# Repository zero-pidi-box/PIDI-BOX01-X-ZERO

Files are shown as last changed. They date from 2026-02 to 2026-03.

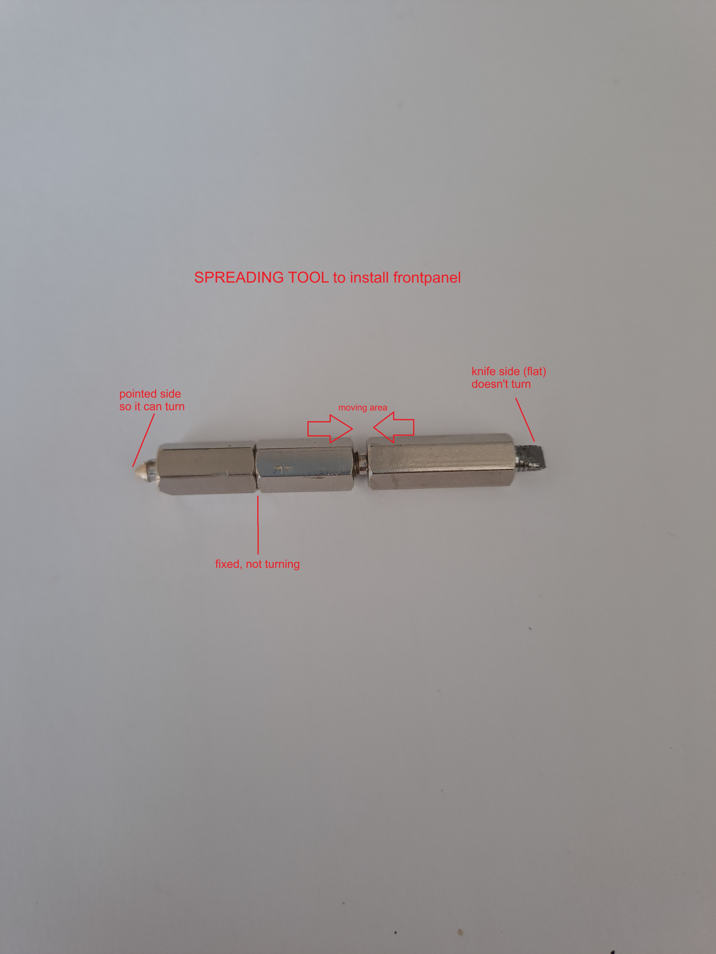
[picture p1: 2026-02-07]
DOCUMENTS all/MECHANICAL and Drawings/PIDI-BOX-spreading tool .jpg

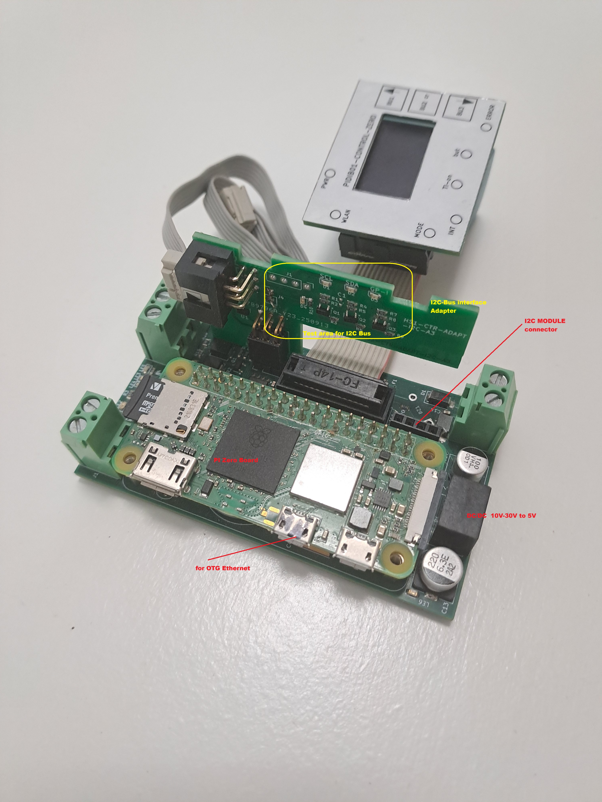
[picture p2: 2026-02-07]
MODULES/CONTROLLER-PI/PI-ZERO-installed.jpg

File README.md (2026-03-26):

# PIDI-BOX01
# A PI-ZERO 2W based modular DIN Rail controller SYSTEM

## OVERVIEW:
Instead of using one controller box with a fixed number of IO’s, 
this system is modular,  
The controller module contains a minimum of interfaces and is expandable with a lot of
* IO MODULES like:  
* **RELAYS /SSR ,**
* **optical INPUTS,**
* **ANALOG inputs,**
* **light sensors RF-transceivers** 
* and much more.

All modules are connected to the controller module via a I2C-Bus.  
Flat cable 6 pin IDC.  
The i2c-bus is 5V buffered:  GND, +5V supplied by the controller  
SDA,SCL and a bidirectional line, usable for interrupts or any control.  
**System supply voltage:  12 V DC (the Controller module only: 10 to 28V)**  

### **Mechanical:**  
DIN Rail enclosures:   Camdenboss CNMB/2/KIT and CNMB/3/KIT  
make sure you use this enclosures, all board are designed for that enclosures !!  

---  
---   

#### **MODULES:**

**PI Zero 2W based controller:**  

CNMB enclosure Size 3:  53,4mm  
    
TERMINALS:  
2 pole terminal: Supply voltage: 10V DC to 24V DC (this module only, or 5V with USB-C adapter)  
2 pole terminal: digital OPTO-INPUT  
3 pole terminal: 1-WIRE interface  
All terminals support 26-12AWG calbles

Front Panel with:
3 touch keys,  
128x64 OLED display  
and 6 led’s (reverse mounted)

**On board:**  
RTC 3132 with Bat. CR2032, status led’s, beeper, I2C driver for external bus,  
I2C buffer, DC/DC converter 12 to 5V 3A.  
Front panel connecto.  
   
**PI Zero 2w module socket**. 
   
**IO:**  
1x digital OPTO in  
1x 1-WIRE interface (GND, sig.,+5V)  
1x UART 4 pin header (no terminal)  
1x I2C-BUS  6 pin  IDC socket.  
 
---  

**DIGITAL 6 port  Relays  (on):**

CNMB enclosure Size 2:  36mm  
Supply voltage: 12V DC  
2x 6 pole terminal for power and RELAY outs  
IO Controller  PCF8574A  (PCF8574)  
After PW-on all relays in off state. Is controlled by bit 7.  
**Front panel** with 6 TEST BUTTONs for the outputs and status LED’s  

---  

**DIGITAL 6 port OPTICAL  INPUTS:**

CNMB enclosure Size 2:  36mm  
Supply voltage: 12V DC  
2x 6 pole terminal for power and INPUTS  
IO Controller  PCF8574A  (PCF8574)  
Front panel with 6 TEST BUTTONs for the outputs and status LED’s  

---  

**ADC 4 CHANNEL (ADS1115)  potential-free inputs:**  
  
CNMB enclosure Size 2:  36mm  
Supply voltage: 12V DC  
2 pole terminal for power  
6 pole terminal for 4 channels of ADC (4), GND and power source.  
    
Internal power source (200mA) 4-8V DC (for sensors on analog 0 to 3)  
  
ADC input and power source are potential free from the system.  
The I2C interface is isolated from the system bus  
 with a **ADUM1250** from Analog Devices.  

There are two versions of the ADC 4:  
A1 is assembled and tested.  
A2 only is available as a KICAD design and has not yet been assembled or tested.  
The A2 version is optimized and can be addressed via  
**four I2C addresses**:    
0x48: ADDR Pin with  GND , 0x49: ADDR Pin with   VDD  
0x4A: ADDR Pin with   SDA, 0x4B: ADDR Pin with   SCL  

---  

**This was just a short summary for quick information.**      
For more details please read the documentation  
available  in the directory DOCUMENTS.  
From time to time I will add individual documentation or data sheets.  

**General information:**  
The hardware I am designing since 3 years for a garden watering system  
in different versions.  
All modules have been tested in reality.  
Code and documents are  **without any guarantee** for any user.

**NO  VDE, CE or other certificates are available.**   
Do not use relay outputs and inputs with high voltage or on main supply.

**All printed boards are designed with KICAD 9**  
including labels, front panels and some drawings for buttons breakthroughs.  
There are no bom's for the boards.  
They should be generated by the user themselves in KICAD.

**Module BOM’s are available in the documents area.**  

**Al outputs or inputs** are designed for low voltage up to 24V, relays up to 48V.   
All analog and direct inputs are ESD protected (TVS 12 V bidirectional)
Not all components are fully optimized, it’s up to the users to do that.

**Meaning of the project name:**

   **PIDI-BOX**  is the project name.  
   That means : Raspberry **PI** Zero **DI**nrail **-BOX**  

**Where to get all Parts?**  
The printed boards I always order from  JLCPCB  <https://jlcpcb.com/es?from=Wolfgang>  
Quality and service is excellent, parts are inexpensive with a very fast delivery.  
![]()

90% of the parts (IC, led ..)  I bought via AliExpress. 

The **CNMB** enclosures you **only can get from a Camdenboss distributor**.  
The 5.08mm Terminals you can buy from camdenbos or other manufacturers.

**Just by the way:**  
I developed the system for myself. In a fiew places it is not optimally dimensioned.  
It's up to you to optimize.  
For me it is sufficient because everything works in practical use.

I would be happy to hear from interested co-developers or users of my hardware.  
That would be an incentive for me to continue and expand the system with additional hardware.  
By the way, documentation is not intended for production.  
Therefore only the most necessary in my opinion.  
There are many documents and clues in the photos or as text.  
Before you start, try to understand my ideas, then the documentation should be enough.  
All GERBER Files are actual, so you can start an assembly imediately.  

With the age of 76,  I don't know how much longer I can work on the project.  
I would be happy if someone continued it.  

If you badly need help, here my special project e-mail :  <PIDI-BOX01@gmx.net>.  
I will try to respond as soon as possible, but it can take a while.  
Wolfgang Mansfeld 02-2026

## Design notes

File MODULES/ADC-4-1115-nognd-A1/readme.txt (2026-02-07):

This Directory contains the BOM to build the MODULE.
Enclosures, other mechanicals like screws, nuts, cables, distance holders
and the assembled BOARDS e.g.  

The BORDS used will have their own bom list in the KICAD directories.
It is up to the designer to generate them.

If availabe,  videos/fotos for the module can be located here.

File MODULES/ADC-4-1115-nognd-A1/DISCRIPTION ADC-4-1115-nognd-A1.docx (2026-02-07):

General preliminary description of the 4 channel Analog Modul

System PIDI-BOX-01

DATAS:

ADC 4 CHANNEL (ADS1115) potential-free inputs:

CNMB enclosure Size 2: 36mm

Supply voltage: 12V DC

2 pole terminal (26-12AWG) for power

6 pole terminal (26-12AWG) for 4 channels of ADC (4), GND

and internal, potential free power source (200mA) 4-8V DC

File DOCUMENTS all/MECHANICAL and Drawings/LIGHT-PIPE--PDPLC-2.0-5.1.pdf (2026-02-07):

# LIGHT-PIPE used for PIDI-BOX Modules

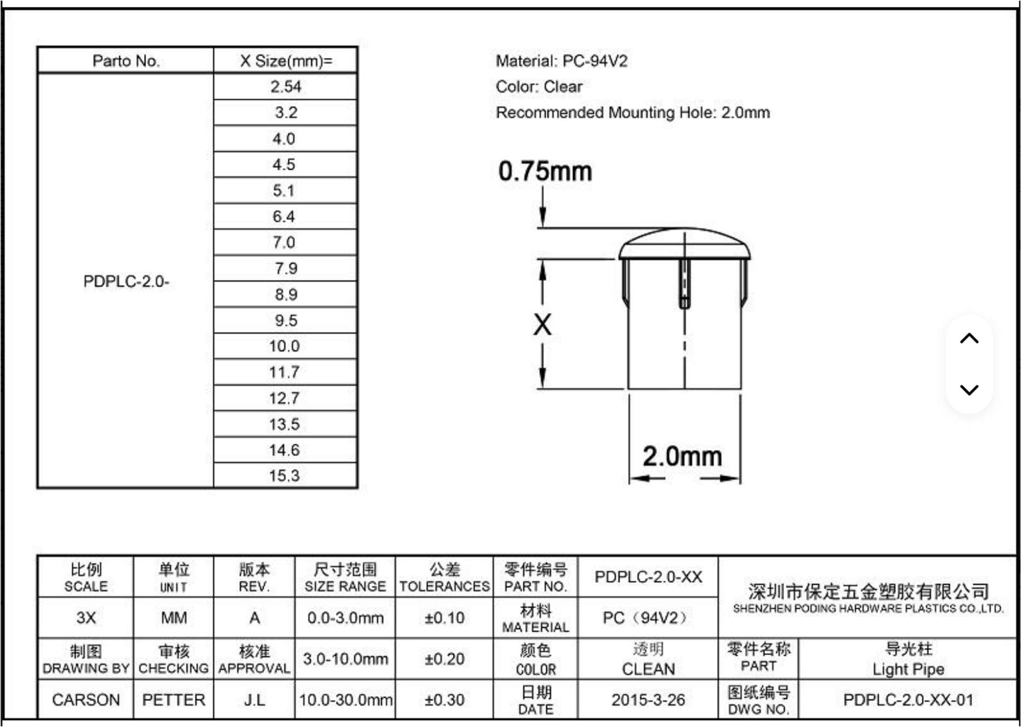
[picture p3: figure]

X = 5,1mm, part no: PDPLC-2.0-5.1
Link : https://podingcorp.en.alibaba.com/productgrouplist-820925231/%C3%B81_0_2_0mm.html
Available on AliExpress as well !!!

Shenzhen Poding Hardware Plastics Co., Ltd. or chose other manufacturers

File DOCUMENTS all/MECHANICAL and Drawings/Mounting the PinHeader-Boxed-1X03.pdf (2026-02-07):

## Mounting the PinHeader-Boxed-1X03

## 2.54 horizontal Wuerth_61200621721

Used on the following PCBs:

PIDI-BOX-01-ADAPT-I2C-A1, PIDI-BOX-01-IO-6-CTRL74-A1

The pin headers for the external I2C bus must be mounted very carefully. To do this, it is necessary to seal the socket with a double-sided adhesive strip before soldering approx. 0.3mm thickness, so that it does not tilt during soldering.
Due to the adhesive strip (as in the photo), the socket is automatically not directly on the board. Thus, the socket is a little further
away from the PCB guide.

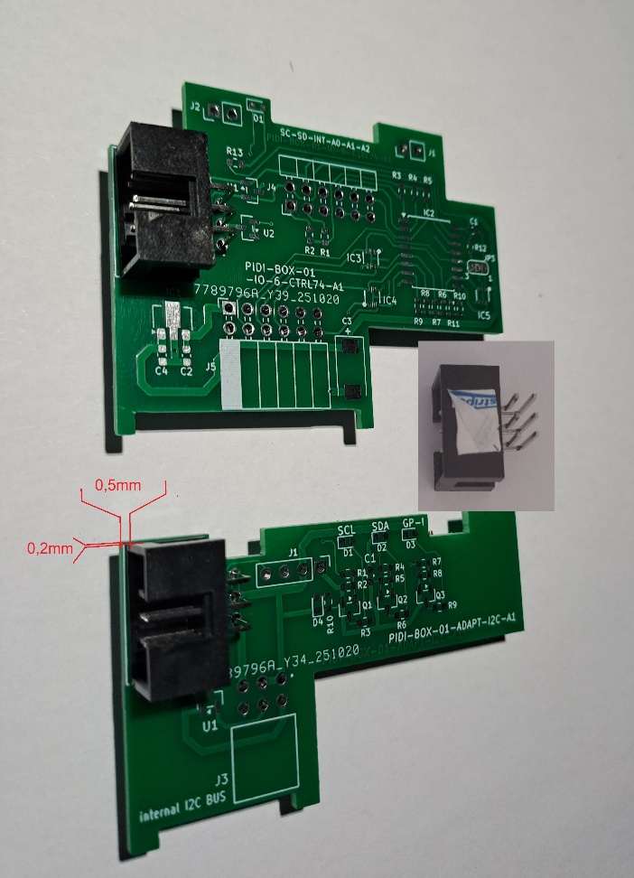
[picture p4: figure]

About the photo:
Distances from the PCB edges:

Links
to the breakthrough in the housing: 0.5mm +0.1
Top
to the case : 0.2mm.

The dimensions apply to all PCBs with this I"C-Bus pin header.

The socket on the right shows how the double-sided adhesive strip should be mounted CENTRALLY.

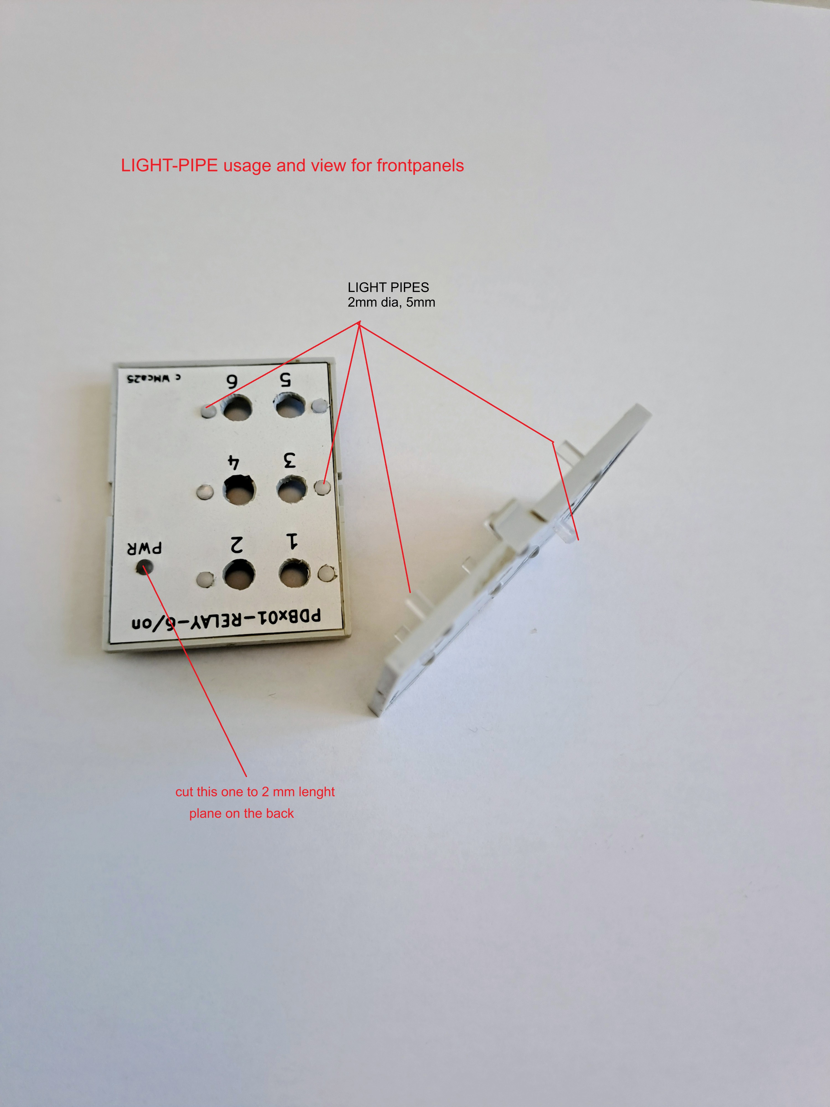
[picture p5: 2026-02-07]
DOCUMENTS all/MECHANICAL and Drawings/MODULES used LIGHT-PIPE.jpg

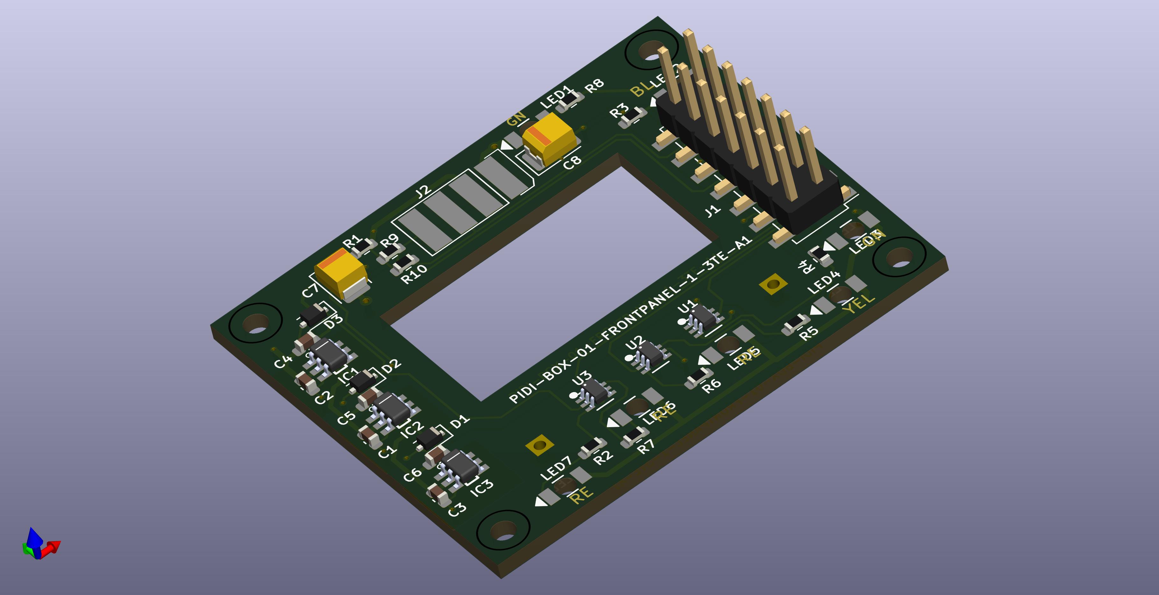
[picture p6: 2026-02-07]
KICAD_BOARDS/PIDI-BOX-01-FRONTPANEL-1-3TE-A1/PIDI-BOX-01-FRONTPANEL-1-3TE-A1.jpg

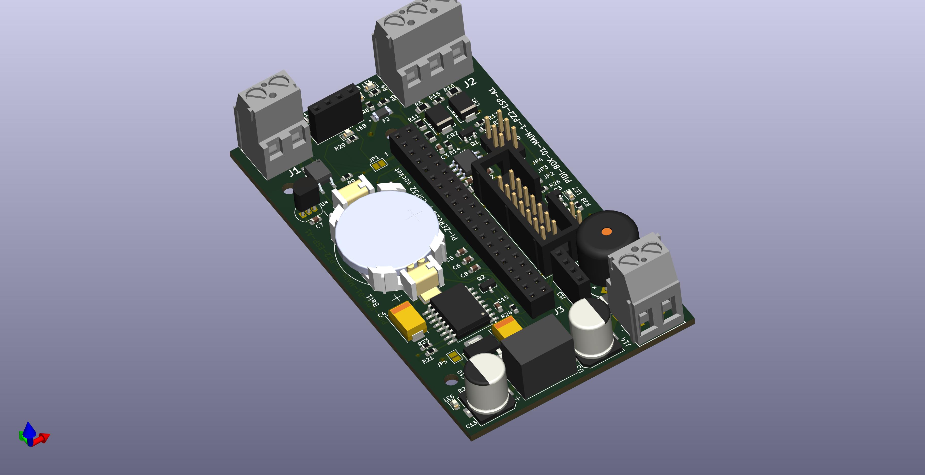
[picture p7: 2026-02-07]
KICAD_BOARDS/PIDI-BOX-01-MAIN-1-PZ2-ESP-A1/PIDI-BOX-01-MAIN-1-PZ2_ESP-A1.jpg

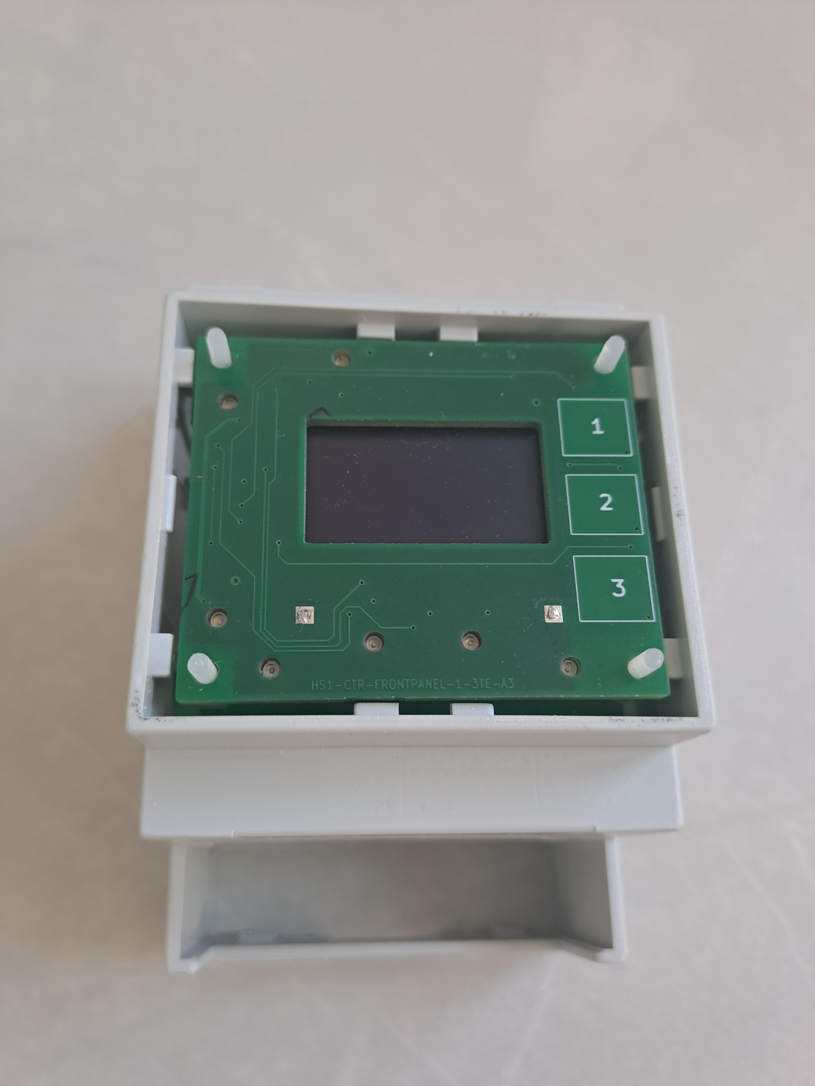
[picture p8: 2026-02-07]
FOTOS and 3D/3TE-displ-mounting 2.jpg

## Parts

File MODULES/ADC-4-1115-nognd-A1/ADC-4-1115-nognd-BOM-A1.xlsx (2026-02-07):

ADC-4-1115-nognd-BOM-A1
POS | DESCRIPTION | PARTNUMBER | Qty | MANUFACTURER | DISTRIBUTOR | Internet
1 | Enclosure DinRail (2M) | CNMB/2/KIT | 1 | Camdenboss | Reichelt DE/ES | https://www.camdenboss.com
1 | Assembled PIDI-BOX board ADC main | PIDI-BOX-01-ADC-4-MAIN-A1 |  | own KICAD board | none | none
1 | Assembled PIDI-BOX board I2C Interface | PIDI-BOX-01-ADAPT-I2C-A1 |  | own KICAD board | none | none
1 | Drilled frontplate from CNMB/2/KIT | from CNMB/2/KIT |  | Camdenboss | none | none
1 | LED 2mm green to install in frontplate | any |  | any | any | any
2 | wire to connect for LED | any |  | any | any | any

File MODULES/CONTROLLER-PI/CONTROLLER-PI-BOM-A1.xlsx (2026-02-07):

System-CONTROLLER-PI-BOM-A1
POS | DESCRIPTION | PARTNUMBER | Qty | MANUFACTURER | DISTRIBUTOR | Internet
1 | (3M) DIN Rail Module Box Cover | CNMB/3/PC - CLEAR | 1 | Camdenboss | Reichelt DE/ES | https://www.camdenboss.com
2 | Enclosure DinRail (3M) | CNMB/3/KIT | 1 | Camdenboss | Reichelt DE/ES | https://www.camdenboss.com
3 | Assembled PIDI-BOX board SYSTEM Controller | PIDI-BOX-01-MAIN-1-PZ2_ESP-A1 | 1 | own KICAD board | none | none
4 | Assembled PIDI-BOX board I2C Interface | PIDI-BOX-01-ADAPT-I2C-A1 | 1 | own KICAD board | none | none
5 | Assembled PIDI-BOX FRONTPANEL with OLED a | PIDI-BOX-01-FRONTPANEL-1-3TE-A1 | 1 | own KICAD board | none | none
6 | PIDI-BOX display mounting frame | PIDI-BOX-01-DISPLAY-MOUNTINGFRAME-A1 | 1 | own KICAD board | none | none
7 | Flatcable 100mm with 2 IDC connectors 14pin | none | 1 | buy or assemble on your own | Ali Express/others | none
8 | M2 Nylon PCB Standoff 5mm, thread 6mm + screw | any supplier (ali express) | 4 |  | any supplier (ali express)
9 | M2,5 spacer bolt 8mm len, internal thread only | any supplier (ali express) | 4
10 | M2,5 spacer bolt 8mm len, internal thread only | any supplier (ali express) | 8
11 | M2,5 x 6mm screws
12 | PI ZERO Board without HEADER | PI Zero 2W | 1 | Raspberry | any
13 | Header 2X20 pins , pitch 2,54 | any
 | Make sure to order PI Zero 2W without header.
 | The 40 pin header must be soldered on the DOWNSIDE of the module
 | The orignal , for HUTS, is upside. Wrong for this project.

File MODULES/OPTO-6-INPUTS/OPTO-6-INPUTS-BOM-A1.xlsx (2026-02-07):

OPTO-6-INPUTS-BOM-A1
POS | DESCRIPTION | PARTNUMBER | Qty | MANUFACTURER | DISTRIBUTOR | Internet
1 | Enclosure DinRail (2M) | CNMB/2/KIT | 1 | Camdenboss | Reichelt DE/ES | https://www.camdenboss.com
2 | Assembled PIDI-BOX board OPTO 6 in main | PIDI-BOX-01-DIGIN-6-OPTO-MAIN-A1 | 1 | own KICAD board | none | none
3 | Assembled PIDI-BOX board 6 button and led keypad | PIDI-BOX-01-RELSW-6-BUTTONS-A1 | 1 | own KICAD board | none | none
4 | Assembled PIDI-BOX board side adapter for keypad | PIDI-BOX-01-IO-6-SIDEB-A1 | 1 | own KICAD board | none | none
5 | Assembled PIDI-BOX board I2C int, 6 IO controller | PIDI-BOX-01-IO-6-CTRL74-A1 | 1 | own KICAD board | none | none
6 | Drilled frontplate from CNMB/2/KIT / 6 buttons | frontplate from CNMB/2/KIT | 1 | own modified/drilled | none | none

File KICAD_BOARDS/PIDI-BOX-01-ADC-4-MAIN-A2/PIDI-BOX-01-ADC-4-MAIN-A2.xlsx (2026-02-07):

Reference | Qty | Value | Footprint | DNP
C1,C3,C4,C5,C6,C7,C8,C9,C11,C13,C15,C16,C17,C18,C21 | 15 | 100nF | Capacitor_SMD:C_0603_1608Metric
C2,C10,C20 | 3 | 100uF | Capacitor_SMD:CP_Elec_8x10.5,Capacitor_Tantalum_SMD:CP_EIA-3528-21_Kemet-B,Capacitor_Tantalum_SMD:CP_EIA-6032-28_Kemet-C
C12 | 1 | 10uF | Capacitor_SMD:C_0805_2012Metric
C14,C19 | 2 | 4,7uF | Capacitor_SMD:C_0805_2012Metric
CR1,CR2,CR3,CR4,CR5 | 5 | SM6T12CA | MYlib_GLOBAL:SMB_STM
D1 | 1 | LED rt | LED_SMD:LED_0603_1608Metric
D2,D3 | 2 | LED gn | LED_SMD:LED_0603_1608Metric,LED_THT:LED_D3.0mm
D4 | 1 | US2BA | Diode_SMD:D_SMA
IC1 | 1 | HCPL-354-000E | MYlib_GLOBAL:HCPL-354-000E
J1 | 1 | Conn_01x10_Pin | Connector_PinSocket_2.54mm:PinSocket_1x10_P2.54mm_Vertical
J2 | 1 | Conn_02x03_Odd_Even | Connector_PinHeader_2.54mm:PinHeader_2x03_P2.54mm_Vertical
J3 | 1 | Conn_02x02_Odd_Even | Connector_PinHeader_2.54mm:PinHeader_2x02_P2.54mm_Vertical
J4,J5 | 2 | Conn_02x01 | Connector_PinHeader_2.54mm:PinHeader_1x02_P2.54mm_Vertical
J6,J7 | 2 | CTB0709_3 | MYlib_GLOBAL:CTB07093
J8 | 1 | CTB0709_2 | MYlib_GLOBAL:CTB07092
J9,J10 | 2 | Conn_01x01 | Connector_PinHeader_2.54mm:PinHeader_1x01_P2.54mm_Vertical
JP1 | 1 | Jumper_2_Open | Jumper:SolderJumper-2_P1.3mm_Open_Pad1.0x1.5mm
L1 | 1 | 6,8uH | Inductor_SMD_Wurth:L_Wurth_WE-GF-3225
PS1 | 1 | IA1209S-2WS | Converter_DCDC:Converter_DCDC_XP_POWER-IAxxxxS_THT
Q1 | 1 | BC817 | Package_TO_SOT_SMD:SOT-23
R1,R10,R24,R25,R26,R27 | 6 | 10 | Resistor_SMD:R_0603_1608Metric
R2,R3,R7,R8,R9 | 5 | 4K7 | Resistor_SMD:R_0603_1608Metric
R4 | 1 | 5K6 | Resistor_SMD:R_0603_1608Metric
R5,R6 | 2 | 100 | Resistor_SMD:R_0603_1608Metric
R11,R12,R13,R14,R29,R30,R31 | 7 | 10K | Resistor_SMD:R_0603_1608Metric
R15,R16,R17,R18 | 4 | 820 | Resistor_SMD:R_0603_1608Metric
R19 | 1 | 8K2 | Resistor_SMD:R_0603_1608Metric
R20,R21,R22,R23 | 4 | 1K5 | Resistor_SMD:R_0603_1608Metric
R28 | 1 | 6K8 | Resistor_SMD:R_0603_1608Metric
RV1 | 1 | 500 | Potentiometer_SMD:Potentiometer_Bourns_3314G_Vertical
RV2,RV3,RV4,RV5 | 4 | 1K | Potentiometer_THT:Potentiometer_Bourns_3296W_Vertical
U1 | 1 | AMS1117-3.3 | Package_TO_SOT_SMD:SOT-223-3_TabPin2
U2 | 1 | ADuM1250 | Package_SO:SOIC-8_3.9x4.9mm_P1.27mm
U3 | 1 | AMS1117CD | Package_TO_SOT_SMD:SOT-223-3_TabPin2
U4 | 1 | ADS1115IDGS | Package_SO:TSSOP-10_3x3mm_P0.5mm

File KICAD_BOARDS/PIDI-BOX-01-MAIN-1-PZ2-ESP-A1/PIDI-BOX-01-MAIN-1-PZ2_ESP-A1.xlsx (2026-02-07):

Reference | Value | Qty | Footprint
C1,C2,C5,C6,C7,C8,C10,C11,C12,C14,C15,C16,C19 | 100nF | 13 | Capacitor_SMD:C_0603_1608Metric
R4,R9,R13,R15,R25,R26,R28,R30,R31 | 4K7 | 9 | Resistor_SMD:R_0603_1608Metric
R3,R6,R7,R8,R16,R17,R19,R29 | 1K5 | 8 | Resistor_SMD:R_0603_1608Metric
R5,R10,R11,R12 | 2.2 | 4 | Resistor_SMD:R_0805_2012Metric
LE1,LE4,LE7,LE8 | red | 4 | LED_SMD:LED_0603_1608Metric
R21,R23,R24 | 10K | 3 | Resistor_SMD:R_0603_1608Metric
R14,R20,R27 | 100 | 3 | Resistor_SMD:R_0603_1608Metric
R1,R2,R22 | 2K7 | 3 | Resistor_SMD:R_0603_1608Metric,Resistor_SMD:R_0805_2012Metric
JP2,JP3,JP4 | 0 | 3 | Resistor_SMD:R_0805_2012Metric
Q1,Q3 | BSS138 | 2 | Package_TO_SOT_SMD:SOT-23
LE3,LE5 | blue | 2 | LED_SMD:LED_0603_1608Metric
JP1,JP5 | Jumper_2_Open | 2 | Jumper:SolderJumper-2_P1.3mm_Open_Pad1.0x1.5mm
J4,J8 | Conn_01x01_Pin | 2 | Connector_PinHeader_2.54mm:PinHeader_1x01_P2.54mm_Vertical
J1,J14 | CTB0709_2 | 2 | MYlib_GLOBAL:CTB07092
F1,F2 | 1206L075THYR | 2 | MYlib_GLOBAL:1206L05015YR
CR1,CR2 | SM6T12CA | 2 | MYlib_GLOBAL:SMB_STM
C3,C18 | 10nF | 2 | Capacitor_SMD:C_0603_1608Metric
U5 | AMS1117-3.3 | 1 | Package_TO_SOT_SMD:SOT-223-3_TabPin2
U4 | DS18B20 | 1 | Package_TO_SOT_THT:TO-92_Inline
U3 | LC78_05-3.0 | 1 | MYlib_GLOBAL:VREG_LC78_05-3.0
U2 | DS3231M | 1 | Package_SO:SOIC-16W_7.5x10.3mm_P1.27mm
U1 | PCA9517AD_118 | 1 | MYlib_GLOBAL:SOIC127P600X175-8N
R18 | 4.7 | 1 | Resistor_SMD:R_0805_2012Metric
Q2 | BC817 | 1 | Package_TO_SOT_SMD:SOT-23
LE6 | yellow | 1 | LED_SMD:LED_0603_1608Metric
LE2 | green | 1 | LED_SMD:LED_0603_1608Metric
J13 | MODUL / I2C | 1 | Connector_PinSocket_2.54mm:PinSocket_1x04_P2.54mm_Vertical
J12 | Digital out | 1 | Connector_PinHeader_2.54mm:PinHeader_1x02_P2.54mm_Vertical
J11 | Conn_02x07_Odd_Even | 1 | Connector_IDC:IDC-Header_2x07_P2.54mm_Vertical
J9 | Conn_02x03_Odd_Even | 1 | Connector_PinHeader_2.54mm:PinHeader_2x03_P2.54mm_Vertical
J5 | Conn_01x03_Pin | 1 | Connector_PinSocket_2.54mm:PinSocket_1x04_P2.54mm_Vertical
J3 | PI_ZERO_2W/ESP32 | 1 | MYlib_GLOBAL:PIDI_PinSocket_2x20_P2.54mm_Vertical
J2 | CTB0709_3 | 1 | MYlib_GLOBAL:CTB07093
IC1 | HCPL-354-000E | 1 | MYlib_GLOBAL:HCPL-354-000E
FB1 | FerriteBead | 1 | Inductor_SMD:L_2010_5025Metric_Pad1.52x2.65mm_HandSolder
D1 | US2BA | 1 | Diode_SMD:D_SMA
C17 | 100uF | 1 | Capacitor_SMD:CP_Elec_8x10
C13 | 220uF | 1 | Capacitor_SMD:CP_Elec_8x10
C9 | 470UF | 1 | Capacitor_Tantalum_SMD:CP_EIA-7343-31_Kemet-D_Pad2.25x2.55mm_HandSolder
C4 | 470uF | 1 | Capacitor_Tantalum_SMD:CP_EIA-7343-31_Kemet-D
BZ1 | Buzzer | 1 | Buzzer_Beeper:Buzzer_12x9.5RM7.6
Bat1 | BU2032SM | 1 | MYlib_GLOBAL:BAT_BU2032SM-BT-GTR

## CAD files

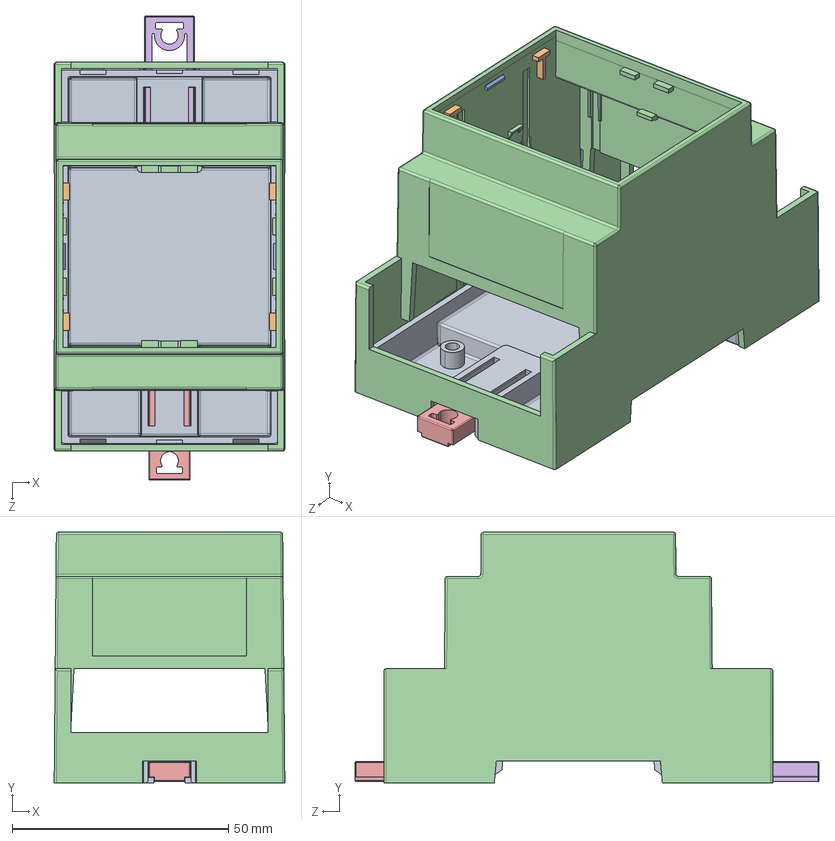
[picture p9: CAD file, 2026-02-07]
DOCUMENTS all/MECHANICAL and Drawings/CNMB-3-2.STEP
53.4 x 58.0 x 107.4 mm
CNMB-3-Base
CNMB-3-2-Top
CNMB-CW
CNMB-CB

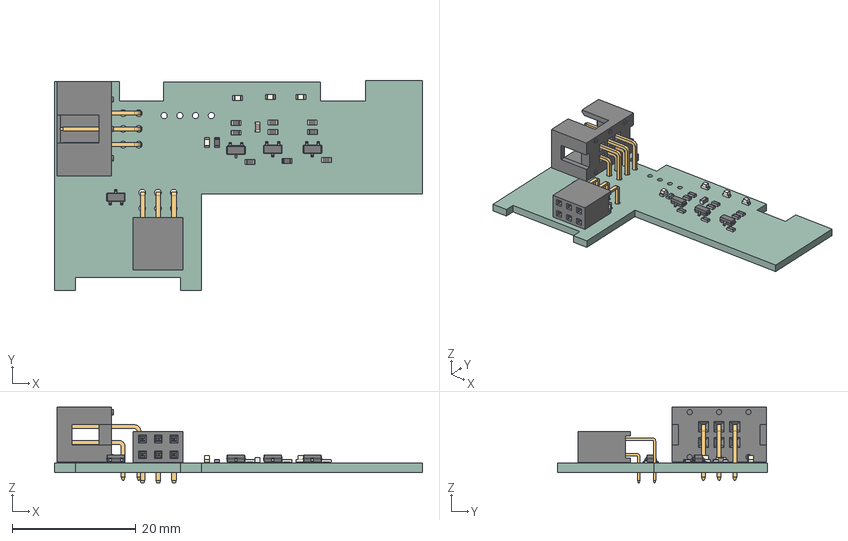
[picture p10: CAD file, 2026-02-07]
KICAD_BOARDS/PIDI-BOX-01-ADAPT-I2C-A1/PIDI-BOX-01-ADAPT-I2C-A1.step
59.5 x 33.9 x 12.2 mm
SOT-23 x 4
R_0603_1608Metric x 10
6130xx243121_PIN x 3
6130xx243121_PIN_G x 3
LED_0603_1608Metric x 4
6120xx21721_PIN x 3
6120xx21721_PIN_LONGUE x 3
C_0603_1608Metric
PIDI-BOX-01-ADAPT-I2C-A1_PCB

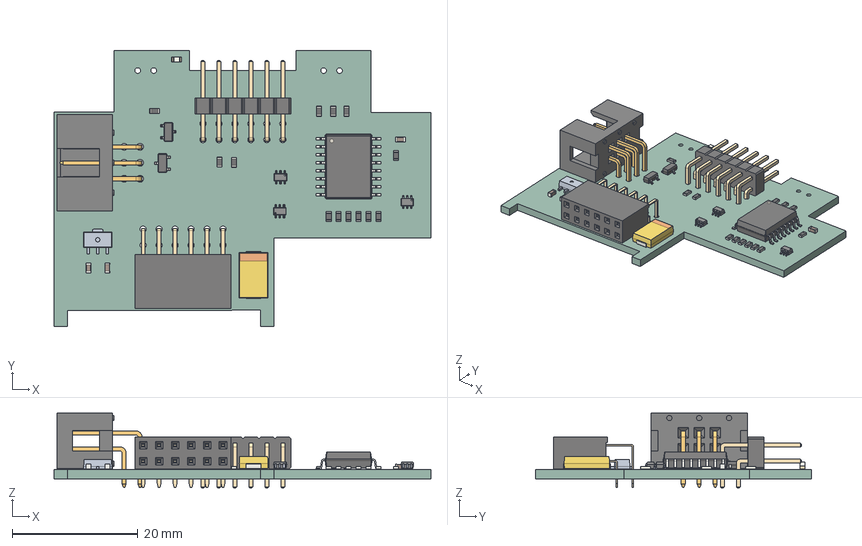
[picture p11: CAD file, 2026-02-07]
KICAD_BOARDS/PIDI-BOX-01-IO-6-CTRL74-A1/PIDI-BOX-01-IO-6-CTRL74-A1.step
59.9 x 43.9 x 11.9 mm
R_0603_1608Metric x 13
PinHeader_2x06_P2.54mm_Horizontal
SOT-23 x 2
6120xx21721_PIN x 3
6120xx21721_PIN_LONGUE x 3
C_0603_1608Metric x 3
PIDI-BOX-01-IO-6-CTRL74-A1 1.14.1
PinSocket_2x06_P2.54mm_Horizontal
PUMH10,115 x 3
LED_0603_1608Metric
CP_EIA-7343-20_Kemet-V
SOIC-16W_7.5x10.3mm_P1.27mm
PIDI-BOX-01-IO-6-CTRL74-A1_PCB

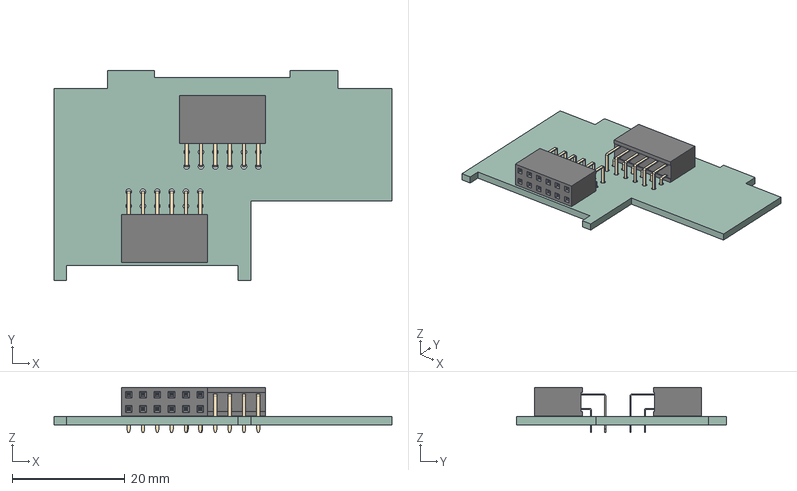
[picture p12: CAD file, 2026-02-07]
KICAD_BOARDS/PIDI-BOX-01-IO-6-SIDEB-A1/PIDI-BOX-01-IO-6-SIDEB-A1.step
59.9 x 37.3 x 7.98 mm
PinSocket_2x06_P2.54mm_Horizontal x 2
PIDI-BOX-01-IO-6-SIDEB-A1_PCB

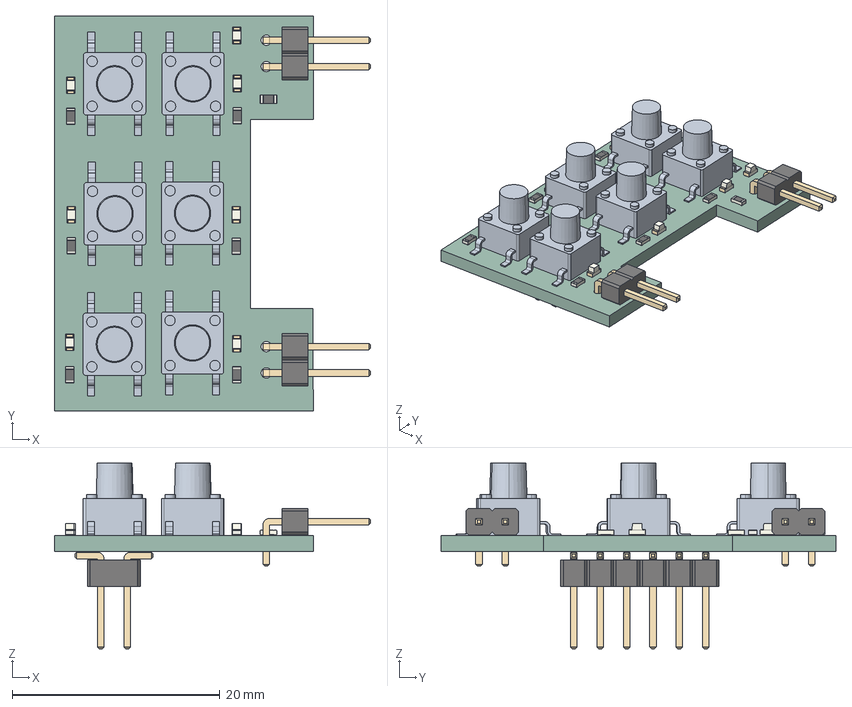
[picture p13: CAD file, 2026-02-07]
KICAD_BOARDS/PIDI-BOX-01-RELSW-6-BUTTONS-A1/PIDI-BOX-01-RELSW-6-BUTTONS-A1.step
30.4 x 38.0 x 17.9 mm
R_0603_1608Metric x 7
LED_0603_1608Metric x 7
SW_tactile-6X6_smd x 6
PinHeader_1x02_P2.54mm_Horizontal x 2
PinHeader_2x06_P2.54mm_Vertical_SMD
PIDI-BOX-01-RELSW-6-BUTTONS-A1_PCB

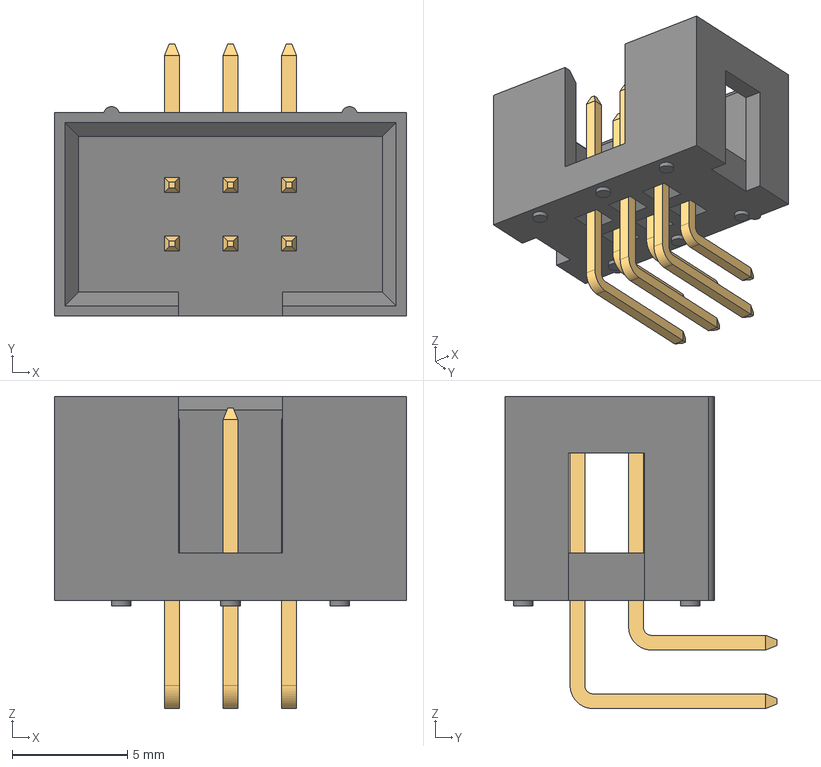
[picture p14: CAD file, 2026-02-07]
KICAD_BOARDS/PIDI_specialparts_library/MYlib_GLOBAL_3dshapes/6120XX21721_61200621721.step
15.3 x 11.8 x 13.6 mm
6120xx21721_PIN x 3
6120xx21721_PIN_LONGUE x 3

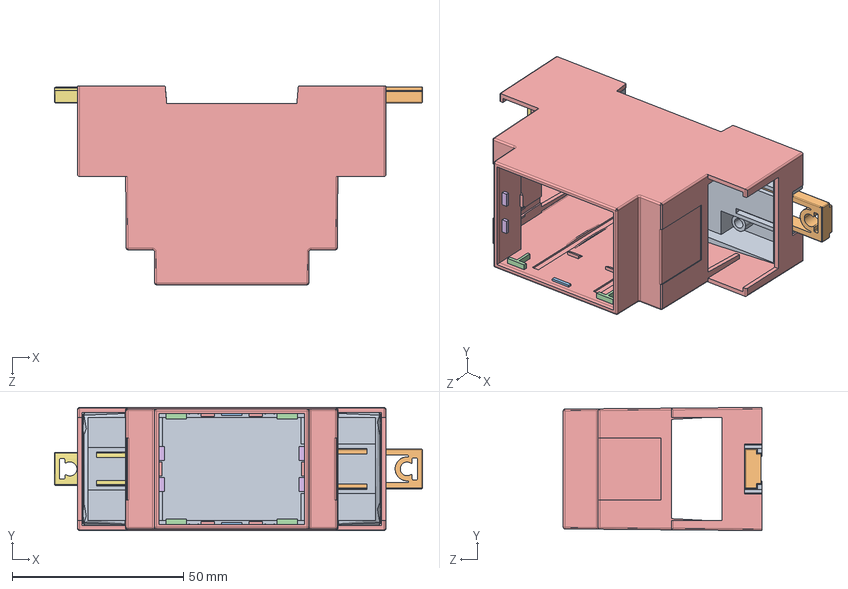
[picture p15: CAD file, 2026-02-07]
DOCUMENTS all/MECHANICAL and Drawings/CNMB-2-2.STEP
107.5 x 36.0 x 58.0 mm
CNMB-CB
CNMB-2-2-Top-1
CNMB-CW
CNMB-2-Base-1

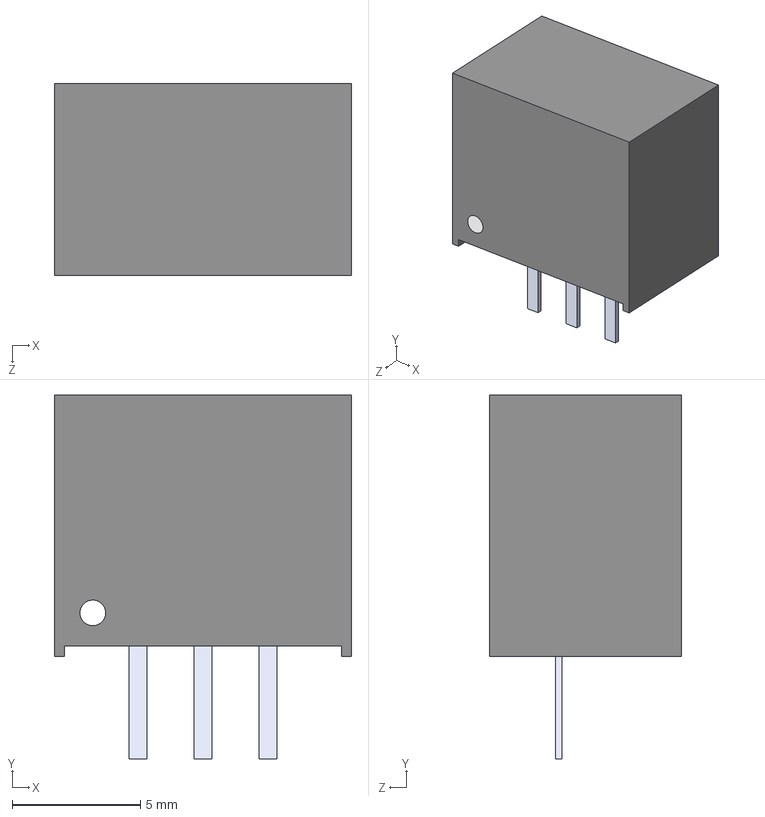
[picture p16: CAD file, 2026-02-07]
KICAD_BOARDS/PIDI_specialparts_library/MYlib_GLOBAL_3dshapes/LC78_05-3.0.step
11.6 x 14.2 x 7.50 mm

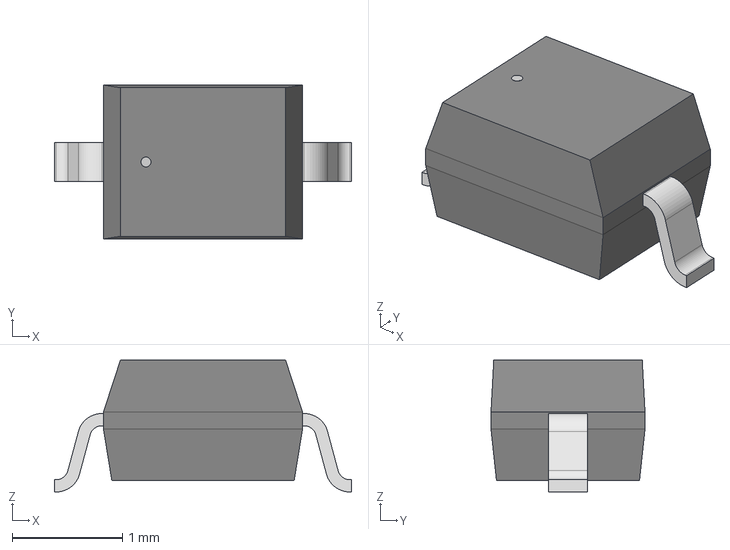
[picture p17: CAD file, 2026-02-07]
KICAD_BOARDS/PIDI_specialparts_library/MYlib_GLOBAL_3dshapes/SOD323_DIO.step
2.69 x 1.40 x 1.20 mm

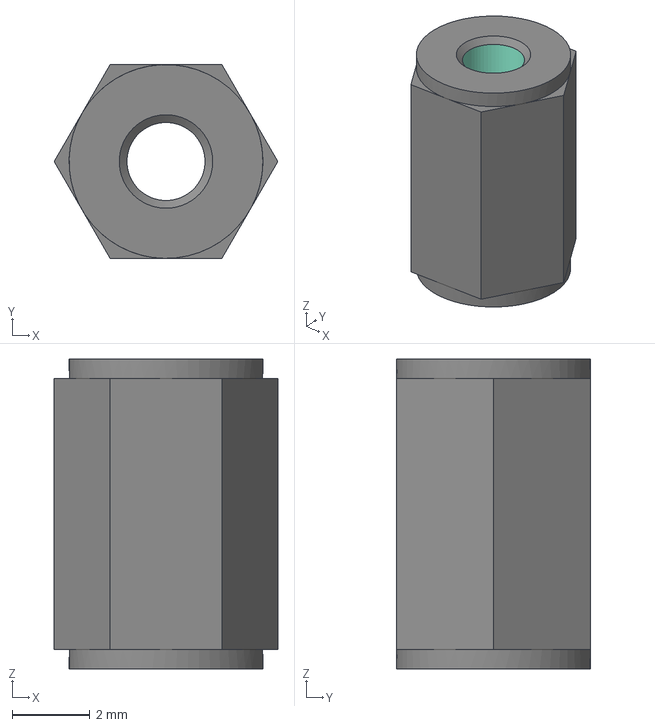
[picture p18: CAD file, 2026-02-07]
KICAD_BOARDS/PIDI_specialparts_library/MYlib_GLOBAL_3dshapes/Download_STEP_970080155+(rev1)(2).stp
5.77 x 5.00 x 8.00 mm

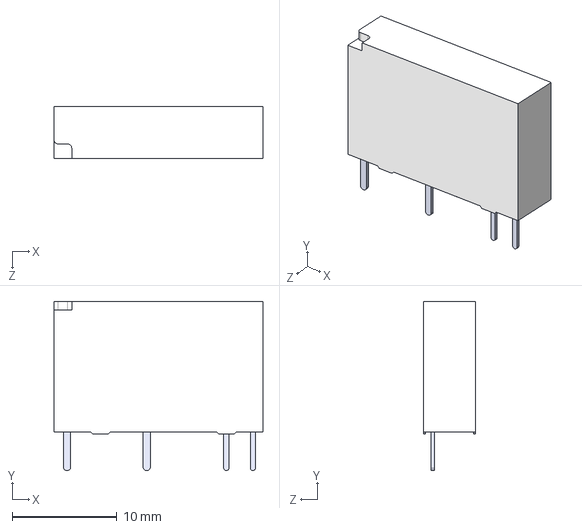
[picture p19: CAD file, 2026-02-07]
KICAD_BOARDS/PIDI_specialparts_library/MYlib_GLOBAL_3dshapes/HF49FD_005-1H12T.step
20.0 x 16.2 x 5.00 mm

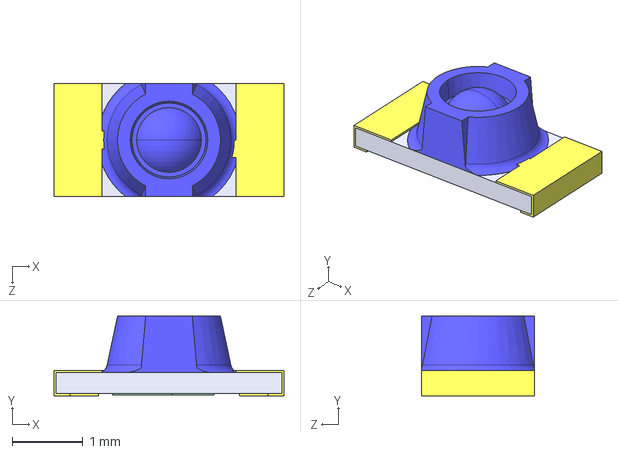
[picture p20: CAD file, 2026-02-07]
KICAD_BOARDS/PIDI_specialparts_library/MYlib_GLOBAL_3dshapes/25-21 Step.STEP
3.26 x 1.13 x 1.60 mm

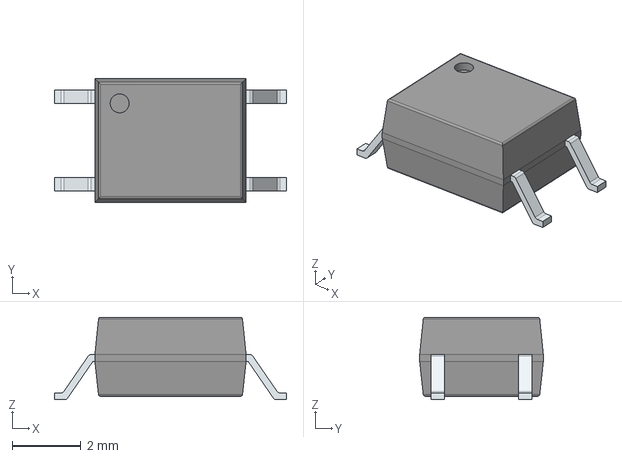
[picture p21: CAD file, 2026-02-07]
KICAD_BOARDS/PIDI_specialparts_library/MYlib_GLOBAL_3dshapes/HCPL-354-000E.stp
6.75 x 3.60 x 2.40 mm
PinsArrayLR

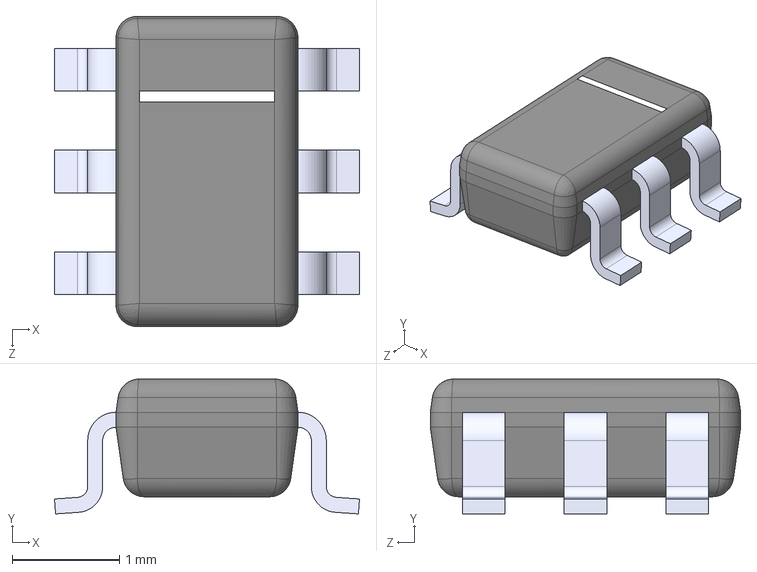
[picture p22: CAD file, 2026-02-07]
KICAD_BOARDS/PIDI_specialparts_library/MYlib_GLOBAL_3dshapes/TTP223-BA6.STEP
2.85 x 1.26 x 2.90 mm

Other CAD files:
KICAD_BOARDS/PIDI_specialparts_library/MYlib_GLOBAL_3dshapes/würth_12pol_613012243121.stp
KICAD_BOARDS/PIDI_specialparts_library/MYlib_GLOBAL_3dshapes/L_Wurth_WE-GF-3225.step
KICAD_BOARDS/PIDI_specialparts_library/MYlib_GLOBAL_3dshapes/SW_tactile-6X6_smd.stp
KICAD_BOARDS/PIDI_specialparts_library/MYlib_GLOBAL_3dshapes/BU2032SM-BT-GTR.STEP
KICAD_BOARDS/PIDI_specialparts_library/MYlib_GLOBAL_3dshapes/1206L075THYR.STEP
KICAD_BOARDS/PIDI_specialparts_library/MYlib_GLOBAL_3dshapes/3214X-1-102E.stp
KICAD_BOARDS/PIDI_specialparts_library/MYlib_GLOBAL_3dshapes/CTB0709_2.stp
KICAD_BOARDS/PIDI_specialparts_library/MYlib_GLOBAL_3dshapes/L_Wurth_WE-GF-4532.step
KICAD_BOARDS/PIDI_specialparts_library/MYlib_GLOBAL_3dshapes/PCA9517AD_118.step
KICAD_BOARDS/PIDI_specialparts_library/MYlib_GLOBAL_3dshapes/PUMH10,115.STEP
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

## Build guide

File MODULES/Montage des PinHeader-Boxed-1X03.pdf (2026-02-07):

## Montage des PinHeader-Boxed-1X03

## 2,54-horizontal-Wuerth_61200621721

Auf folgenden PCB’s verwendet:

PIDI-BOX-01-ADAPT-I2C-A1, PIDI-BOX-01-IO-6-CTRL74-A1

Die Pin Header für den externen I2C-Bus müssen sehr sorgfältig montiert werden. Hierzu ist es notwendig die Buchse vor dem Löten mit einem doppelseitige Klebestreifen
ca. 0,3mm Stärke zu fixieren, damit diese sich beim Löten nicht verkantet.
Durch den Klebestreifen (wie im Foto) liegt die Buchse automatisch nicht direkt auf der Platine.
Beim Einbau in ein Gehäuse, ist darauf zu
achten, | dass | der | Führungssteg
entsprechend in den Schlitz gleitet.
Erst dann ist die Platine richtig fixiert.

Zum Foto:
Abstände von den Leiterplatten Kanten:

Links
zum Durchbruch im Gehäuse: 0,5mm +0,1
Oben
zum Gehäuse : 0,2mm.

Die Maße gelten für alle Leiterplatten mit diesem I“C-Bus Pin-Header.

Die Buchse rechts zeigt, wie der
doppelseitige | Klebestreifen | MITTIG


montiert werden muss. Sonst bleibt kein Spalt für den Führungssteg !!!!

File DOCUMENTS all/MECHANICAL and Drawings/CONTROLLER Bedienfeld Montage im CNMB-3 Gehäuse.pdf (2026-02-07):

Bedienfeld Montage:
Controller Modul im CNMB/3/ Gehäuse

Die Nylon Abstandshalter müssen zuerst auf dem Rahmen montiert werden. Dann wird der Rahmen in angegebener Richtung eingebaut Wichtig ist die Position des Rahmens beim Einbau.

Der oene Ausschnitt muss vom I2C Ausschnitt weg zeigen. Wie im Bild.

Der Montagerahmen darf nicht gewaltsam in das Gehäuse gedrückt werden !!!!
Die kleinen Nasen im Plastikgehäuse zur

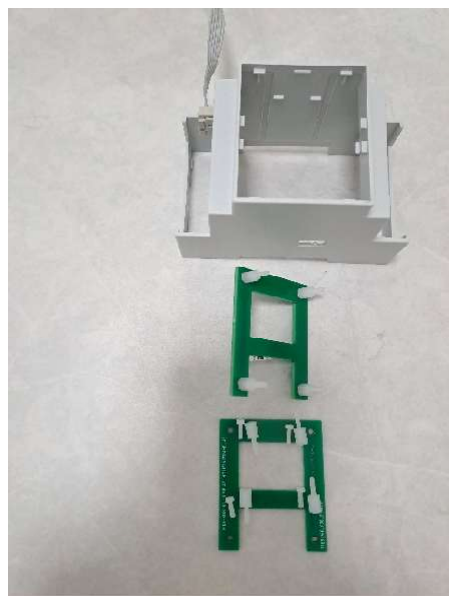
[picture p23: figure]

Arretierung des Rahmens, sind sehr zerbrechlich.

Deshalb solltet Ihr das kleine Eigenbau Werkzeug verwenden.
Das Spreizwerkzeug hilft den Rand des Gehäuses so weit auseinander zu drücken, bis man den Rahmen leicht einsetzen kann.

Spreizen und
dann den
Rahmen von
unten einsetzen

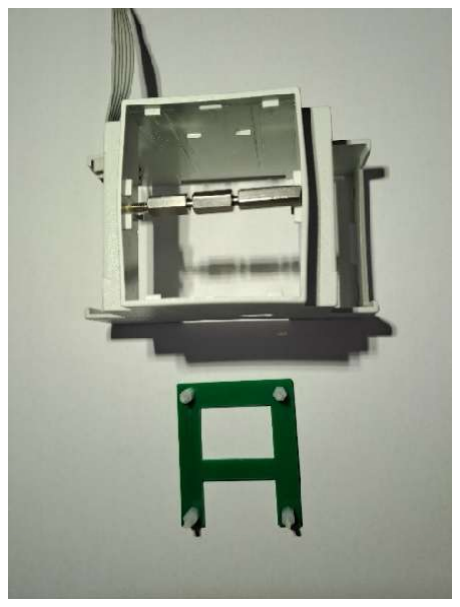
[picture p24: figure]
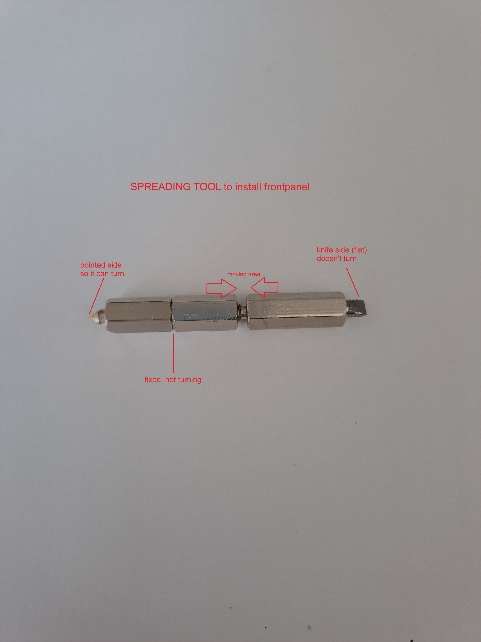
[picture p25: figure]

Danach das Werkzeug vorsichtig entfernen !!

Nun das Bedienfeld auf die 2mm Kunststo Gewinde aufstecken. Bitte beachten: Die Aussparung im Rahmen muss sich links befinden. Denn auf dieser Seite sitzt der Steckverbinder der Leiterplatte.

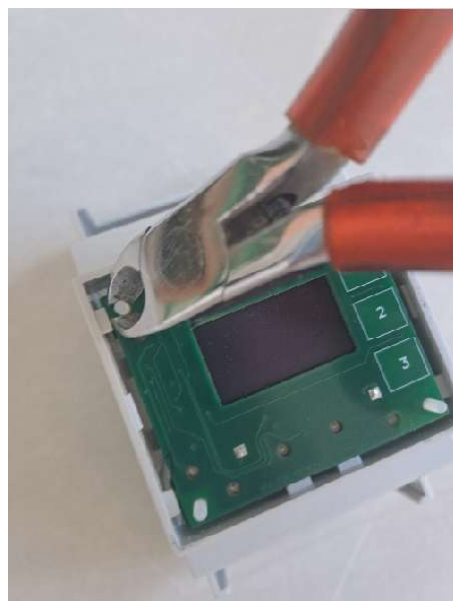
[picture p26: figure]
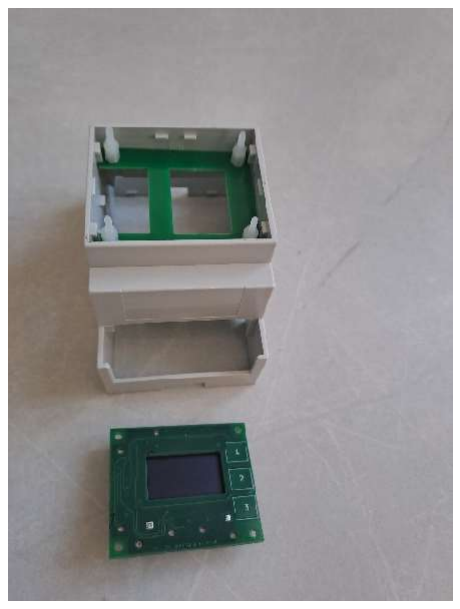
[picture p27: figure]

Die Gewindebolzen bündig mit der Leiterplatte abschneiden.

Die Leiterplatte nicht ankleben oder fixieren. Das Ganze ist schwimmend gelagert und wird mit der durchsichtigen Frontplatte ( zusätzlich zum Gehäuse bestellen, siehe MODULE BOM) abgedeckt.

Auf die Leiterplatte kann eine Beschriftete Folie direkt aufgeklebt werden. Die drei rechten kapazitiven Tasten werden vom Sensor IC automatisch angepasst. Näheres im Dokument.

FERTIG

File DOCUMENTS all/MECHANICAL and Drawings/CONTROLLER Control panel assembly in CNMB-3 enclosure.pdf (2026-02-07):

Control panel Mounting
of the controller module in the CNMB/3/ housing

The nylon spacers must first be mounted on the frame. Then the frame is installed in the specified direction
The position of the frame during installation is important.

The open cutout must face away from the I2C cutout. As in the picture.

The mounting frame must not be forcibly pressed into the housing !!!
The small lugs in the plastic housing for locking the frame are very fragile.


That's why you should use the small DIY tool.
The spreading tool helps to push the edge of the case apart until you can easily insert the frame.

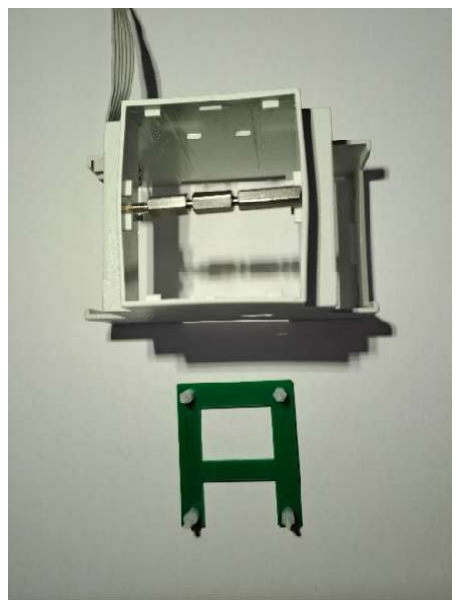
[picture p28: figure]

Spread and then
insert the frame
from below


After that, carefully remove the tool !!

Please note: The recess in the frame must be on the left.

This is because the connector of the printed circuit board is located on this side.
Now attach the control panel to the 2mm plastic thread.

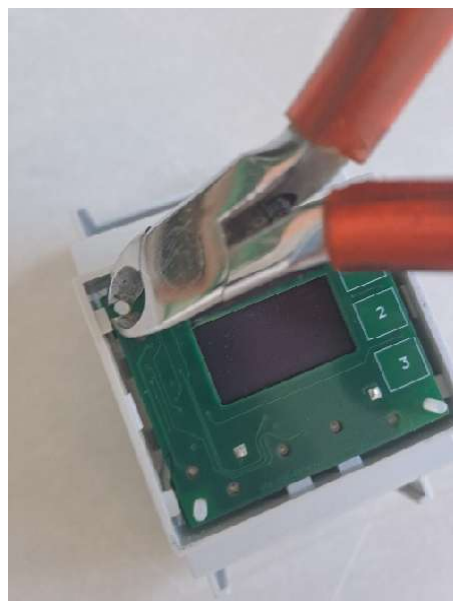
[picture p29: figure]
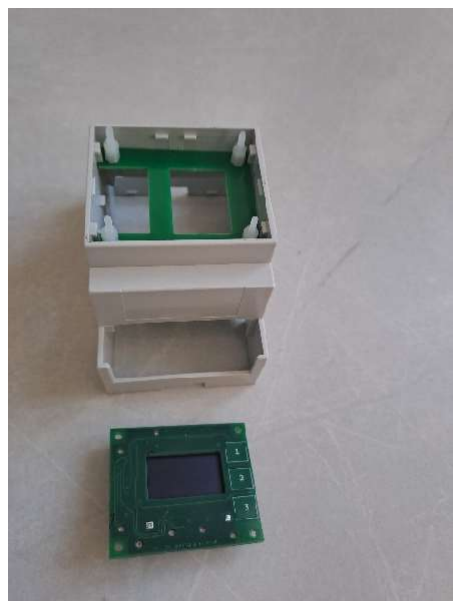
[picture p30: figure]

Cut the threaded bolts flush with the PCB.

Do not glue or fix the PCB. The whole thing is floating
and is covered with the transparent front panel (order in addition to the housing, see MODULE BOM).

A labeled foil can be glued directly to the printed circuit board.
The three right capacitive buttons are automatically adjusted by the sensor IC. More details in the document.

DONE

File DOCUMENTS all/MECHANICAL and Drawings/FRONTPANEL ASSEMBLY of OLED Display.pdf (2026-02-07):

FRONTPANEL OLED Display Assembly on printed circuit board PIDI-BOX-01-FRONTPANEL-1-3TE-A1

Before mounting the OLED display, the two fixing pins must be soldered onto it. This must not protrude on the front after soldering. Otherwise, the panel cannot be installed in the module housing and no labeled foil can be glued on.

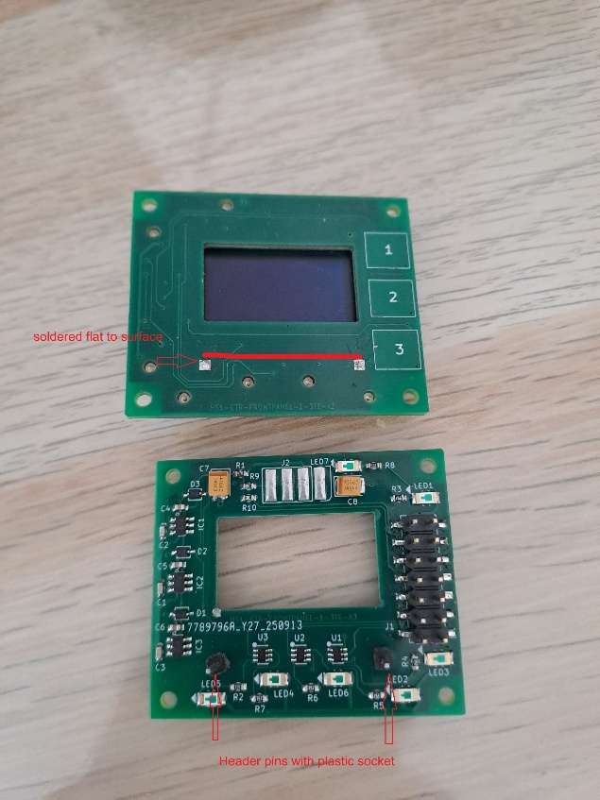
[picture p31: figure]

Individual contacts of a pin strip, which is used to fix the distance of the display, are suitable for this purpose. The display is located on this side on the bases of the pins. On the contact side of the display, this rests on the tantalum capacitors. This means that the distance to the PCB is large enough and fixed.

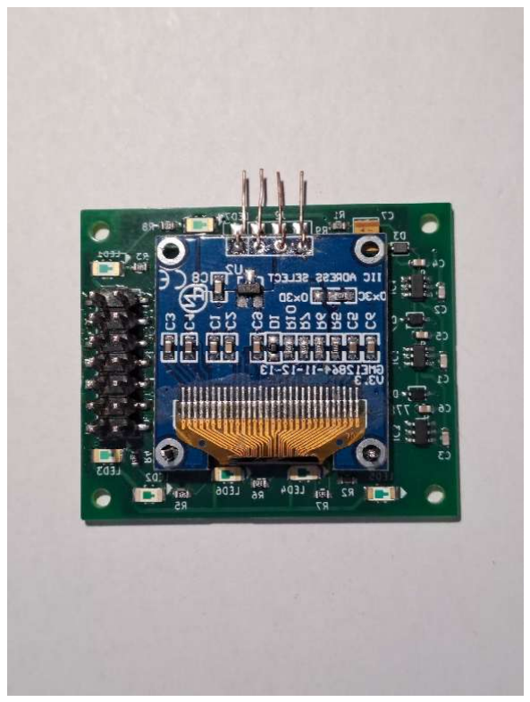
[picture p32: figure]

The GME12864-11-1 display should be ordered without pins, as there are no holes for it. These would be ill-suited for a front-facing labeling film.

Instead of the pins, four copper wires are soldered on.

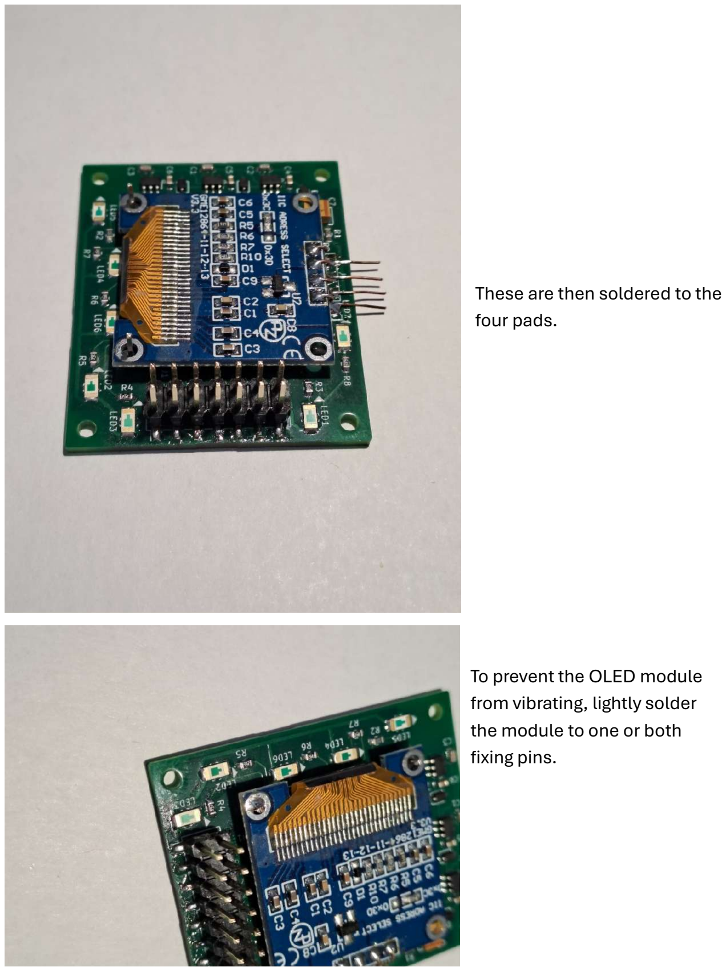
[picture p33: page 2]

These are then soldered to the four pads.

To prevent the OLED module from vibrating, lightly solder the module to one or both
fixing pins.

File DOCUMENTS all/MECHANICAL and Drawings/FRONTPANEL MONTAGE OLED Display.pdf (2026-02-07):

FRONTPANEL OLED Display Montage auf Leiterplatte PIDI-BOX-01-FRONTPANEL-1-3TE-A1

Vor der Montage des OLED Displays müssen auf diesem die zwei Fixierstifte aufgelötet werden. Dies dürfen auf der Frontseite nach dem Löten nicht herausstehen. Sonst kann das Panel nicht im Modul Gehäuse eingebaut werden und keine beschriftete Folie aufgeklebt werden.


Dazu eigenen sich einzelne Kontakte einer Pin Leiste, welcher zur Abstandsfixierung des Displays verwendet wird. Das Display liegt an dieser Seite auf den Sockeln der Pin’s. Auf der Kontaktseite des Displays liegt dieses auf den Tantal Kondensatoren auf. Damit ist der Abstand zur Leiterplatte groß genug und fixiert.

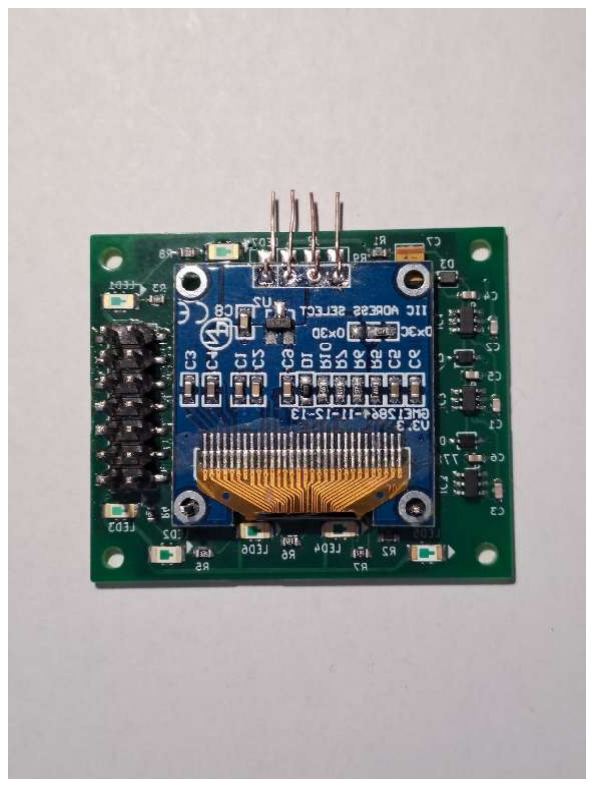
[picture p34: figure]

Das Display GME12864-11-1 sollte ohne stifte bestellt werden, da es dafür keine Bohrungen gibt. Diese wären schlecht geeignet für eine frontseitige Beschriftungsfolie.

Anstelle der Pin’s werden vier Kupferdrähte angelötet.

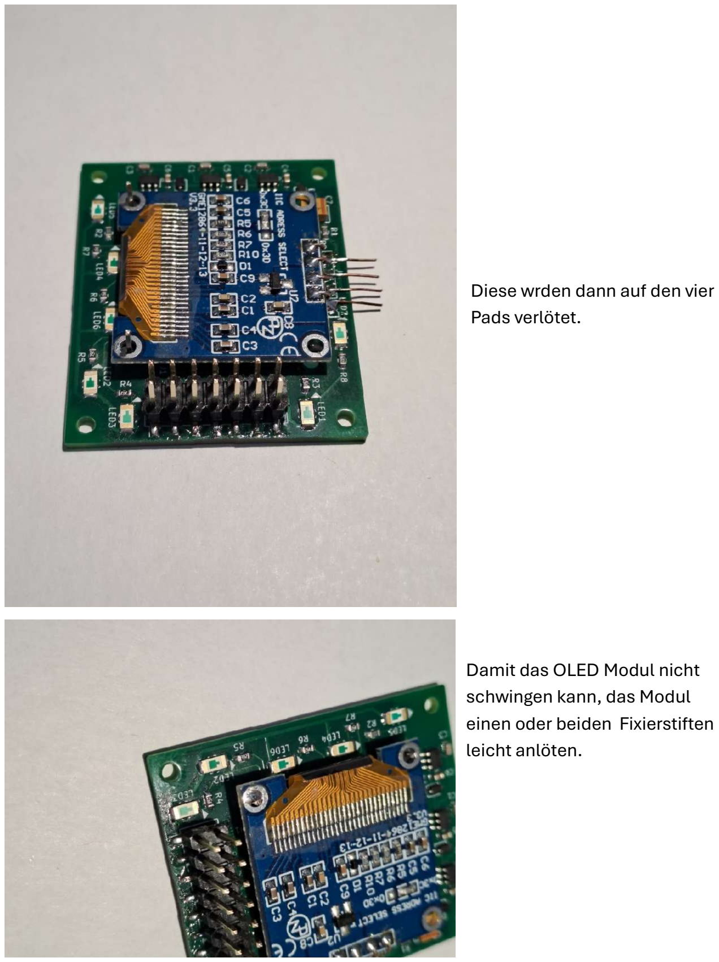
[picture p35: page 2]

Diese wrden dann auf den vier Pads verlötet.

Damit das OLED Modul nicht schwingen kann, das Modul
einen oder beiden Fixierstiften leicht anlöten.

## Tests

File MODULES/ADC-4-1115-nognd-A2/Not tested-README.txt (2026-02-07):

This Version A" of ADC is not tested. Will be done in a few weeks.
Added Additional  I2C-BUS ADDRESSES.
Changed pot for voltage Setting  and changed  general layout.

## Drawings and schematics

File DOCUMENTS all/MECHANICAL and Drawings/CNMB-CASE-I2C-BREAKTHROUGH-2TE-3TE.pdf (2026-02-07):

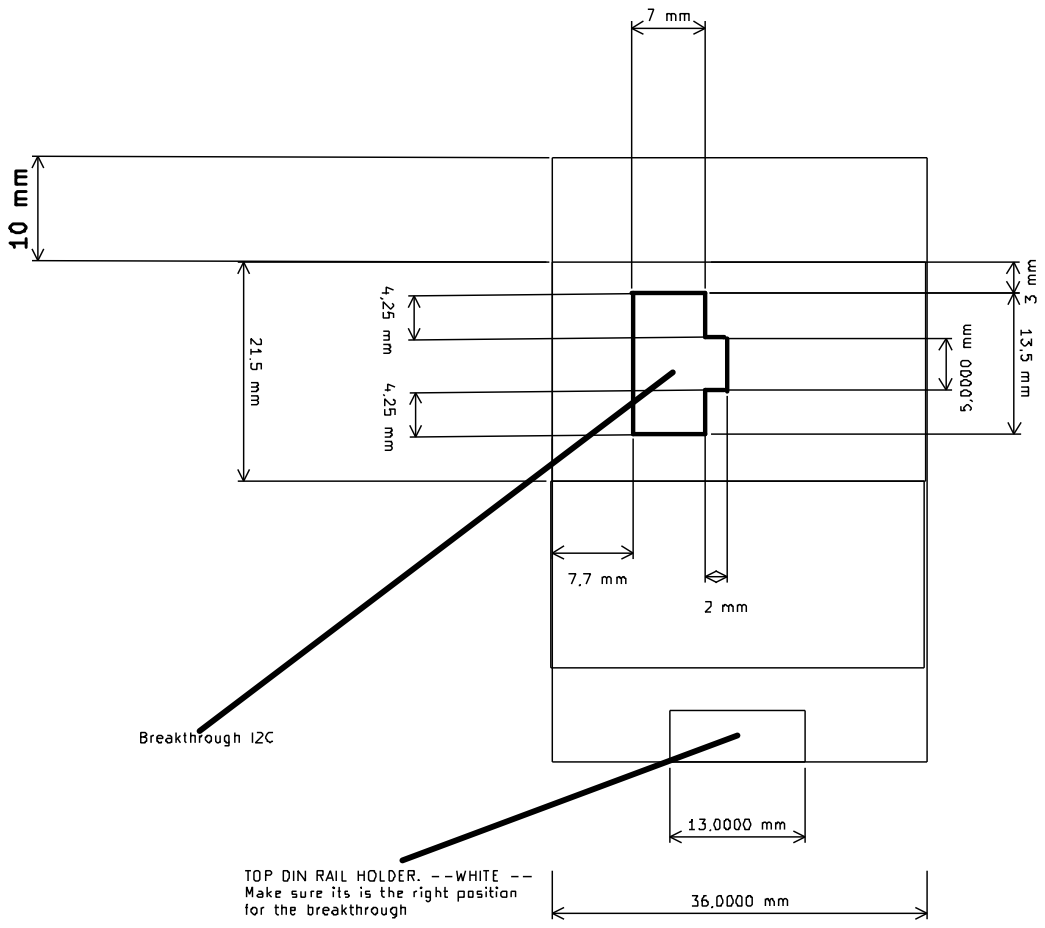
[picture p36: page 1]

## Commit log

2026-02-07 NEW general copy
    here we start
    [1206L075THYR.STEP, 25-21 Step.STEP, 3214X-1-102E.stp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]
2026-02-27 UPDATE from original
    Full update and some new.
    5V USB-C adapter instead of 12 V terminal
    [HS-CTR-REL6-BUT-FRONTPLATE-DRILL.kicad_pcb, HS-CTR-REL6-BUT-FRONTPLATE-DRILL.kicad_sch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]
2026-03-11 ADC4 change
    ADC4 Update Solderjumper 1-2 closed now
    [PIDI-BOX-01-ADC-4-MAIN-A2-B_Cu.gbr, PIDI-BOX-01-ADC-4-MAIN-A2-B_Paste.gbr, PIDI-BOX-01-ADC-4-MAIN-A2-B_Silkscreen.gbr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]
